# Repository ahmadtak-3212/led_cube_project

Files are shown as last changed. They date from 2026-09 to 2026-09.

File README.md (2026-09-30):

# LED cube (formerly "galina")

A **4 × 4 × 4 RGB LED cube**, built twice:

- **V1:** the cube is driven straight from an **FPGA**. The SystemVerilog design scans the cube one LED at a time: it selects a column through a shift register, selects a layer, and applies 8-bit PWM to each colour channel.
- **V2:** the cube sits on a custom KiCad PCB carrying an **Arduino Nano (ATmega328P)**. It uses a charlieplexing library and a set of animations.

🎥 **Demo video:** [`docs/images/Galina_Results.mp4`](docs/images/Galina_Results.mp4). The video is 720p; GitHub shows a download or preview link for it.

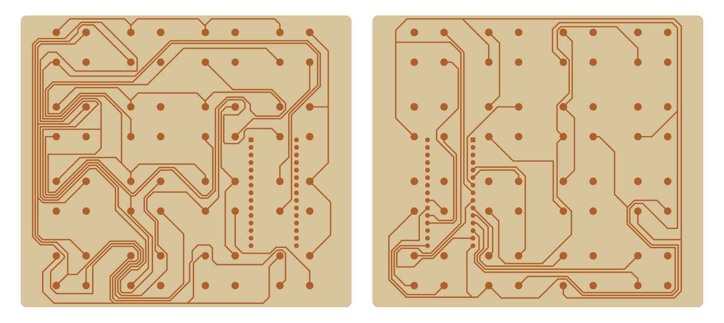
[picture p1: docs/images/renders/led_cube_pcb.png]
V2 PCB, top and bottom

<sub>V2 carrier PCB, rendered from <code>electrical/led_cube_pcb/GBR</code>.</sub>

## Status

| Area | Status |
|---|---|
| FPGA (V1) | ✅ Vivado project, testbenches and four prebuilt bitstreams |
| PCB (V2) | ✅ Routed; Gerbers exported, including a set prepared for a CNC etcher |
| Firmware (V2) | ✅ Animations running (see video) |
| Mechanical | ✅ PCB case, soldering jig, cut files |

## Repository layout

```
led_cube_project/
├── fpga/led_cube_v1/              Vivado project "Galina" (V1)
│   ├── Galina.xpr
│   ├── Galina.srcs/sources_1/new/ top_level.sv, led_driver_fsm.sv, write.sv, pwm.sv
│   ├── Galina.srcs/sources_1/ip/  clk_wiz_0 (clocking wizard)
│   ├── Galina.srcs/sim_1/         testbenches
│   ├── Galina.srcs/constrs_1/     .xdc constraints
│   ├── wcfg/                      saved waveform views for each testbench
│   └── runs/*.bit                 prebuilt bitstreams
├── electrical/led_cube_pcb/       KiCad 6 PCB for V2 (+ GBR/ Gerbers)
├── firmware/led_cube_firmware/    PlatformIO project for V2 (Arduino Nano)
├── mechanical/
│   ├── cad/                       SolidWorks: cube parts, Soldering_Jig.SLDASM
│   ├── cam/                       3D-print (.3mf), CNC-etcher Gerbers
│   └── exports/                   STL (PCB case + cover), SVG (laser-cut soldering jig)
└── docs/images/Galina_Results.mp4
```

## V1: FPGA driver (`fpga/led_cube_v1`)

**Target:** Xilinx Artix-7 **XC7A100T-CSG324** (`xc7a100tcsg324-3`), using the Nexys A7 / Nexys 4 DDR pinout. The 100 MHz clock is on pin E3, the cube connects through Pmod headers **JA** and **JB**, and `btnc`, `sw[15:0]` and `led[15:0]` come from the board.

**How it works:**

| Module | Role |
|---|---|
| `top_level.sv` | Holds the frame buffer `led_cube[4 layers][16 LEDs][24-bit RGB]` and a demo pattern generator. With `sw[0]` on, the cube cycles through white, red, green and blue every 4,000,000 clocks; `btnc` resets it. The board LEDs mirror the switches. |
| `led_driver_fsm.sv` | The scan FSM. For each LED in the current layer, it writes a one-hot 16-bit column pattern into the shift register and then runs a PWM slot for that pixel's RGB value. Each layer gets `MAX_CYCELS_PER_PLANE = 20833` clocks (16 slots of about 1302 clocks), after which it advances `z_level`. |
| `write.sv` | Shifts 16 bits out to a serial-in, parallel-out shift register chain. It drives SER, SRCLK and SRCLR, then pulses the latch. |
| `pwm.sv` | 8-bit PWM of the pixel's R, G and B bytes within one slot |
| `clk_wiz_0` | Divides the 100 MHz board clock down for the driver |

**Pmod pinout:**

| Pmod pin | Signal |
|---|---|
| `ja[0]` | shift-register serial data (SER) |
| `ja[1]` | shift clock (SRCLK) |
| `ja[2]` | shift-register clear (SRCLR, active low) |
| `ja[3]` | latch (RCLK) |
| `ja[4]`, `ja[5]`, `ja[6]` | red, green, blue PWM |
| `jb[3:0]` | one-hot layer select (z = 0…3) |

**Bitstreams** in `runs/` are `Brightness.bit`, `Checker.bit`, `EitherSide.bit` and `Full_Cube_Flash.bit`. Each is a different demo pattern.

**Rebuild or program:**
1. Open `Galina.xpr` in Vivado. The project was saved with **Vivado 2019.2**; newer versions will offer to upgrade it and the `clk_wiz_0` IP.
2. Run synthesis, implementation and bitstream generation.
3. Use Hardware Manager to program the board, or load one of the prebuilt `.bit` files.
4. To simulate, open any testbench in `sim_1` with its matching `.wcfg` from `wcfg/`.

## V2: Arduino carrier PCB (`electrical/led_cube_pcb`)

- KiCad 6, 2 layers, 111 × 98 mm.
- An **Arduino Nano v3** socket, sixteen **2 × 2 headers** (`J0,0` to `J3,3`, one per cube column, 4 leads each), and a 2-pin screw terminal for power.
- Gerbers are in `GBR/`. A copy set up for the desktop CNC etcher is in `mechanical/cam/CNC_Etcher/`.

## V2: firmware (`firmware/led_cube_firmware`)

| Setting | Value |
|---|---|
| Platform | `atmelavr`, board `nanoatmega328new` (Nano with the new bootloader), Arduino framework |
| Sources | `src/Firmware.ino` (animation loop), `src/cubeplex.h` (charlieplexing driver), `src/mappings.h` (pin-to-LED map), `src/niceTimer.h` |

The animations are `randomLed`, `planarSpin`, `fountian`, `trifade`, `shiftSquares`, `tunnel`, `chaseTheDot` and `planarFlop3D`.

```bash
cd firmware/led_cube_firmware
pio run -t upload          # Nano over USB
```

`platformio.ini` also points `lib_extra_dirs` at `~/Documents/Arduino/libraries`. The project doesn't need anything from there, because everything is in `src/`.

> **Credit:** `cubeplex.h`, `mappings.h`, `niceTimer.h` and the animation code in `Firmware.ino` come from **Asher Glick's** charlieplexed RGB cube library (Copyright © 2012 Asher Glick, BSD license; the full text is in `src/LICENCE` and in each file header). My work in V2 is the PCB, the build and the integration.

## Mechanical

| File | What |
|---|---|
| `cad/Soldering_Jig/Soldering_Jig.SLDASM` + `exports/svg/Soldering_Jig/*.svg` | Laser-cut jig that holds LEDs in a 4 × 4 grid while soldering each layer |
| `exports/stl/Galina_PCB_Case.STL`, `Galina_PCB_Cover.STL` | 3D-printed enclosure for the V2 PCB (`cam/3D_Printer/Galina_PCB_Casse.3mf` is the print project) |
| `cad/Galina/Parts/` | Cube part models |

## Reproducing

1. Laser-cut the soldering jig from the SVGs, then solder four 4 × 4 layers of common-lead RGB LEDs and stack them into columns.
2. **V2:** mill or order the PCB from `GBR/`, fit a Nano, plug each column into its 2 × 2 header, and flash the firmware.
3. **V1:** wire the Pmod pins as in the table above to a 16-bit shift-register column driver and four layer drivers, then program a bitstream.

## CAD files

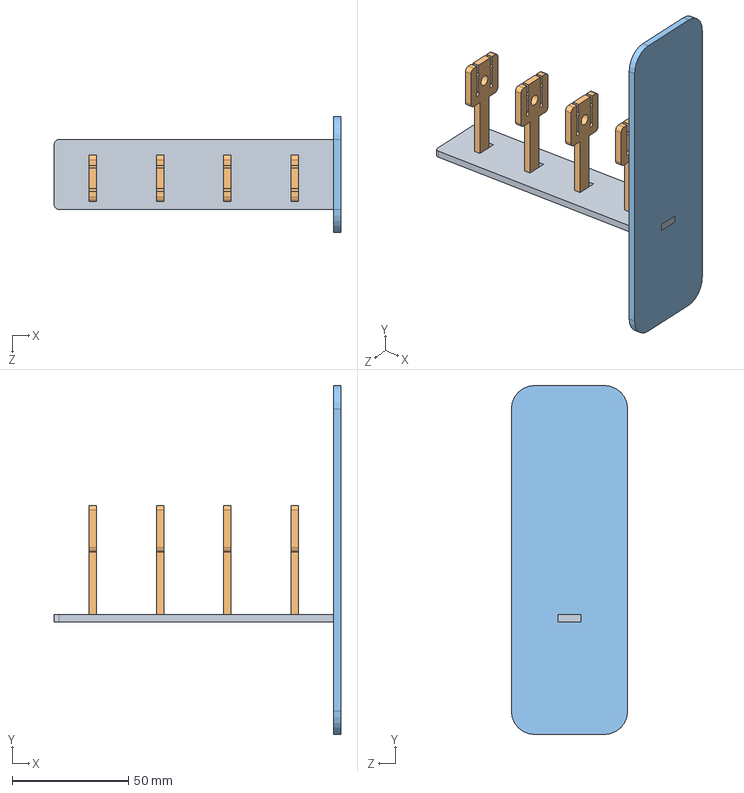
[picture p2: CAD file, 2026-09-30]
mechanical/cad/Soldering_Jig/Soldering_Jig.SLDASM
123.2 x 150.0 x 50.0 mm
LED_Holder_Jig
LED_Jig x 4
LED_Jig_Base

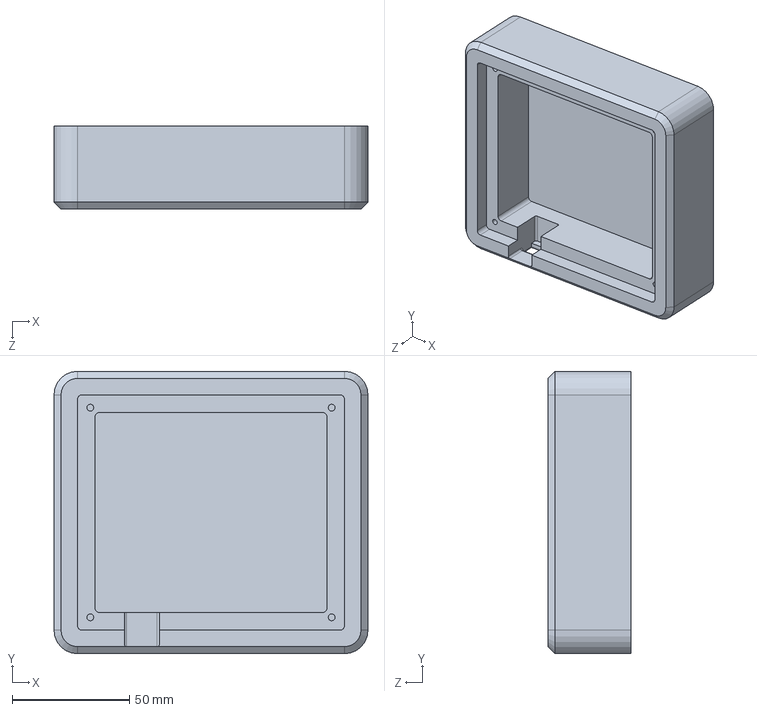
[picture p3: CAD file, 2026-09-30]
mechanical/cad/Galina/Parts/Galina_PCB_Case.SLDPRT
134.0 x 120.5 x 35.5 mm

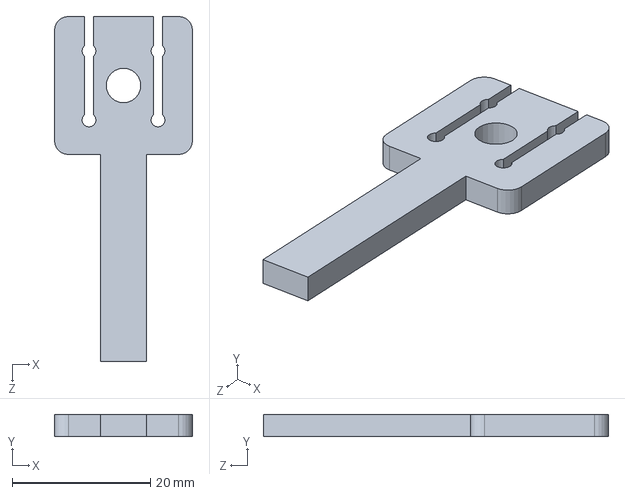
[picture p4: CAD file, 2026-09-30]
mechanical/cad/Soldering_Jig/Parts/LED_Jig.SLDPRT
20.0 x 3.20 x 50.0 mm

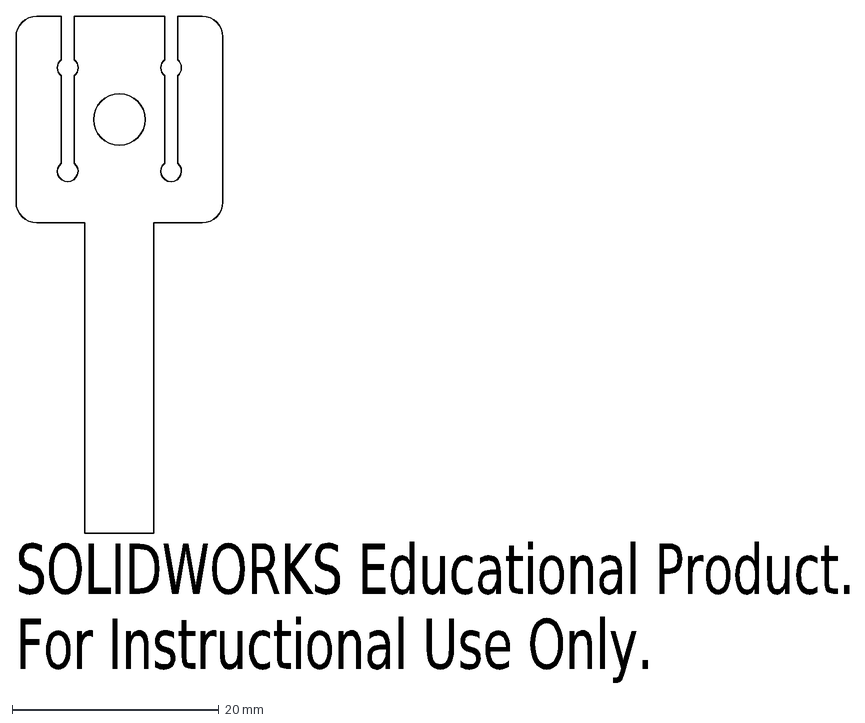
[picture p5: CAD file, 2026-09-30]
mechanical/exports/svg/Soldering_Jig/LED_Jig.DXF
SOLIDWORKS Educational Product.
For Instructional Use Only.

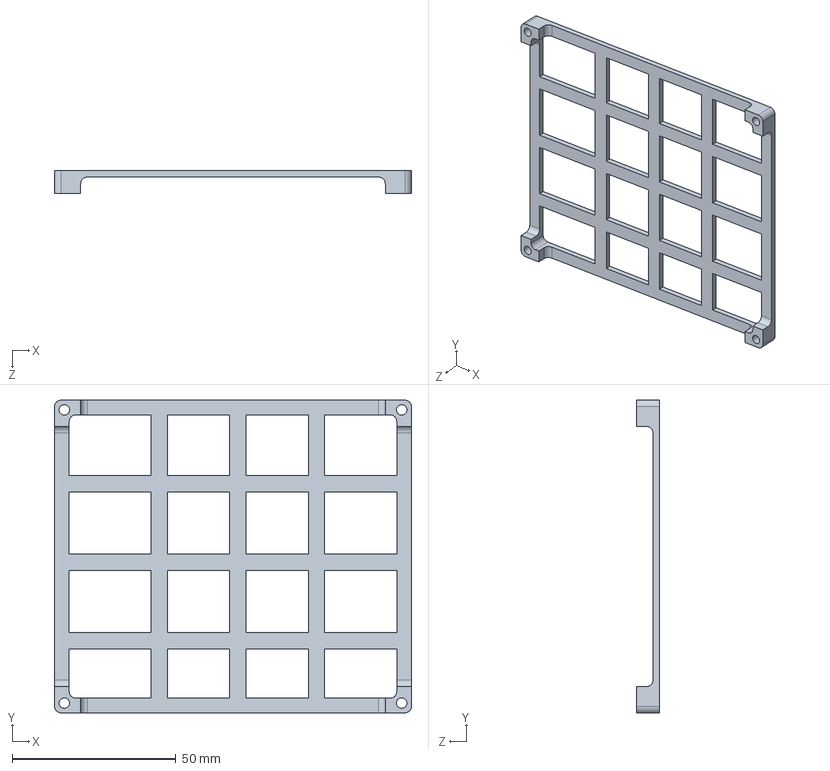
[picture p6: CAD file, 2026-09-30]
mechanical/cad/Galina/Parts/Galina_PCB_Cover.SLDPRT
109.0 x 95.5 x 7.00 mm

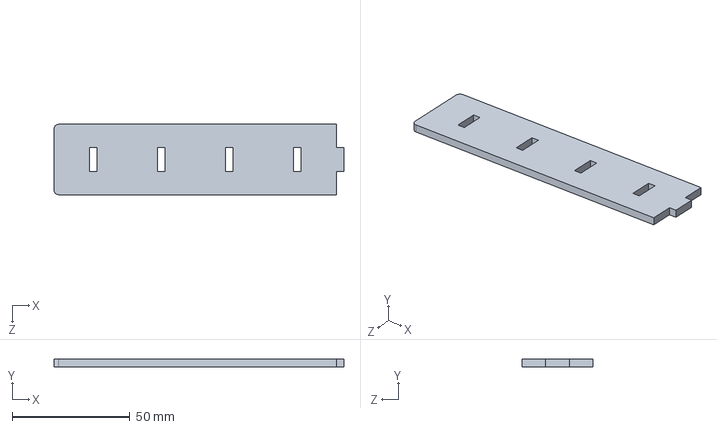
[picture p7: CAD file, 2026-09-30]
mechanical/cad/Soldering_Jig/Parts/LED_Holder_Jig.SLDPRT
123.2 x 3.20 x 30.0 mm

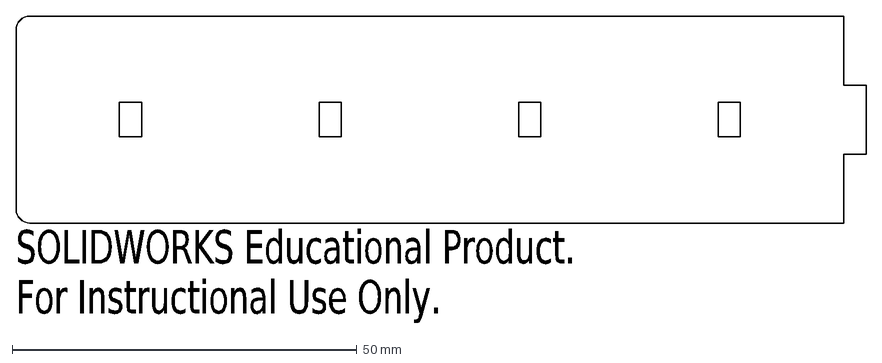
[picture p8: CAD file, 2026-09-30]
mechanical/exports/svg/Soldering_Jig/LED_Holder_Jig.DXF
SOLIDWORKS Educational Product.
For Instructional Use Only.

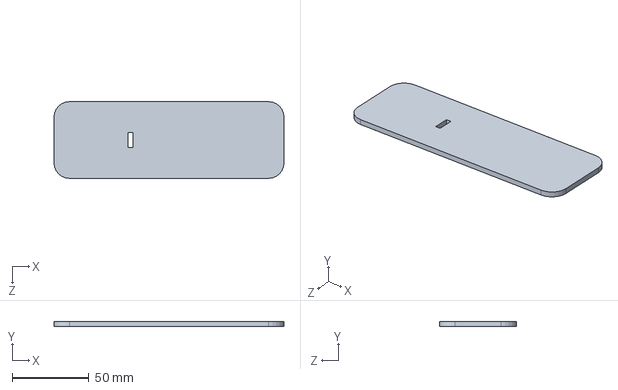
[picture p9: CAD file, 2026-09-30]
mechanical/cad/Soldering_Jig/Parts/LED_Jig_Base.SLDPRT
150.0 x 3.20 x 50.0 mm

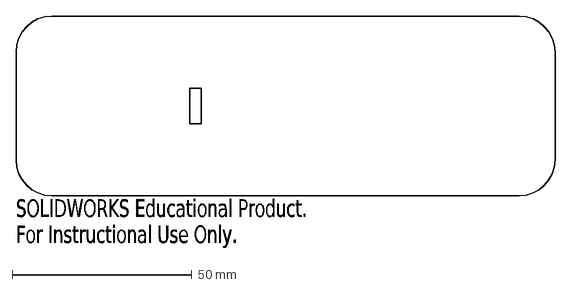
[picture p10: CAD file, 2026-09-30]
mechanical/exports/svg/Soldering_Jig/LED_Jig_Base.DXF
SOLIDWORKS Educational Product.
For Instructional Use Only.

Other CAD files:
mechanical/cam/3D_Printer/Galina_PCB_Casse.3mf
mechanical/exports/stl/Galina_PCB_Case.STL
mechanical/exports/stl/Galina_PCB_Cover.STL

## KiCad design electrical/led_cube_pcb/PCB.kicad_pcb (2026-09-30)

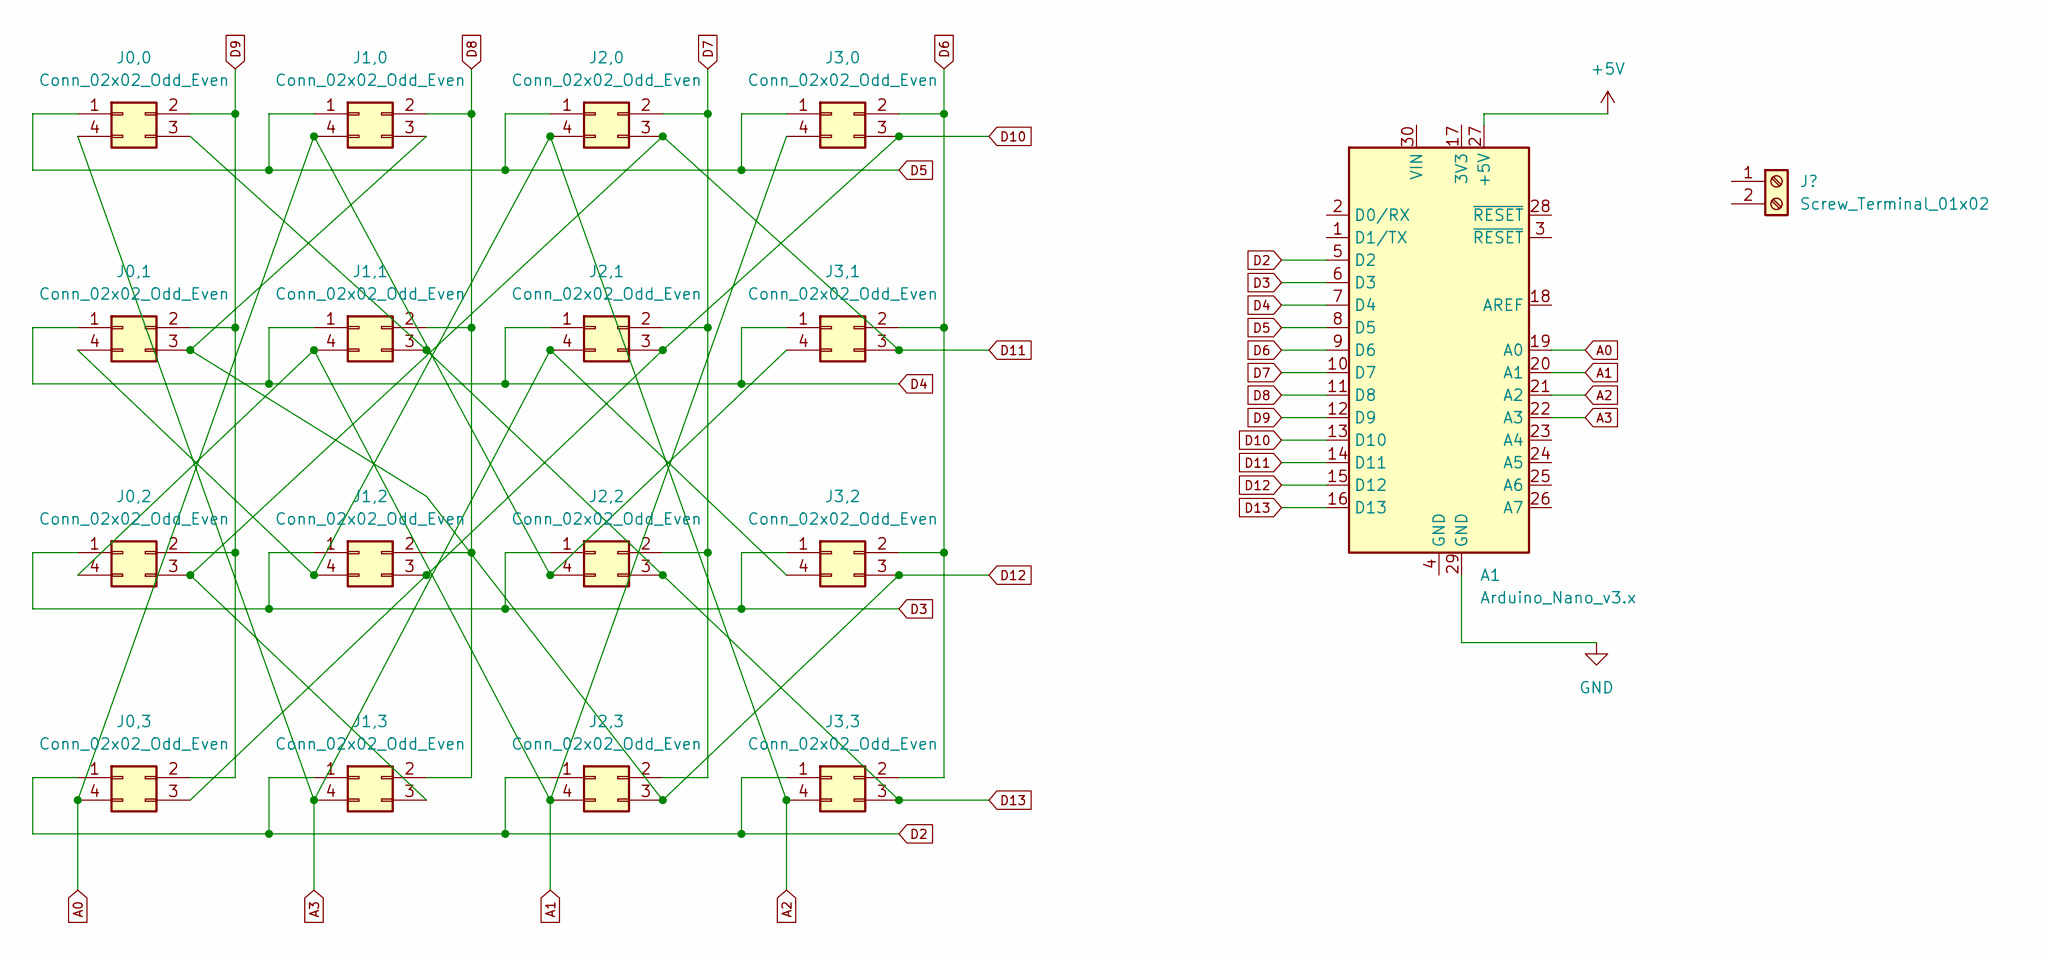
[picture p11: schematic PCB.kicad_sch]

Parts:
A1: Arduino_Nano_v3.x; Arduino_Nano
J0,0: Conn_02x02_Odd_Even
J0,1, J0,2, J0,3, J1,0, J1,1, J1,2, J1,3, J2,0, J2,1, J2,2, J2,3, J3,0, J3,1, J3,2, J3,3: Conn_02x02_Odd_Even; LED_D5.0mm-4_RGB_Square

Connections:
+5V: A1.27 (+5V)
A0: A1.19 (A0), J0,3.4, J1,0.4, J2,2.4, J3,1.4
A1: A1.20 (A1), J0,2.4, J1,1.4, J2,3.4, J3,0.4
A2: A1.21 (A2), J0,1.4, J1,2.4, J2,0.4, J3,3.4
A3: A1.22 (A3), J0,0.4, J1,3.4, J2,1.4, J3,2.4
D2: A1.5 (D2), J0,3.1, J1,3.1, J2,3.1, J3,3.1
D3: A1.6 (D3), J0,2.1, J1,2.1, J2,2.1, J3,2.1
D4: A1.7 (D4), J0,1.1, J1,1.1, J2,1.1, J3,1.1
D5: A1.8 (D5), J0,0.1, J1,0.1, J2,0.1, J3,0.1
D6: A1.9 (D6), J3,0.2, J3,1.2, J3,2.2, J3,3.2
D7: A1.10 (D7), J2,0.2, J2,1.2, J2,2.2, J2,3.2
D8: A1.11 (D8), J1,0.2, J1,1.2, J1,2.2, J1,3.2
D9: A1.12 (D9), J0,0.2, J0,1.2, J0,2.2, J0,3.2
D10: A1.13 (D10), J0,3.3, J1,2.3, J2,1.3, J3,0.3
D11: A1.14 (D11), J0,2.3, J1,3.3, J2,0.3, J3,1.3
D12: A1.15 (D12), J0,1.3, J1,0.3, J2,3.3, J3,2.3
D13: A1.16 (D13), J0,0.3, J1,1.3, J2,2.3, J3,3.3
GND: A1.29 (GND)

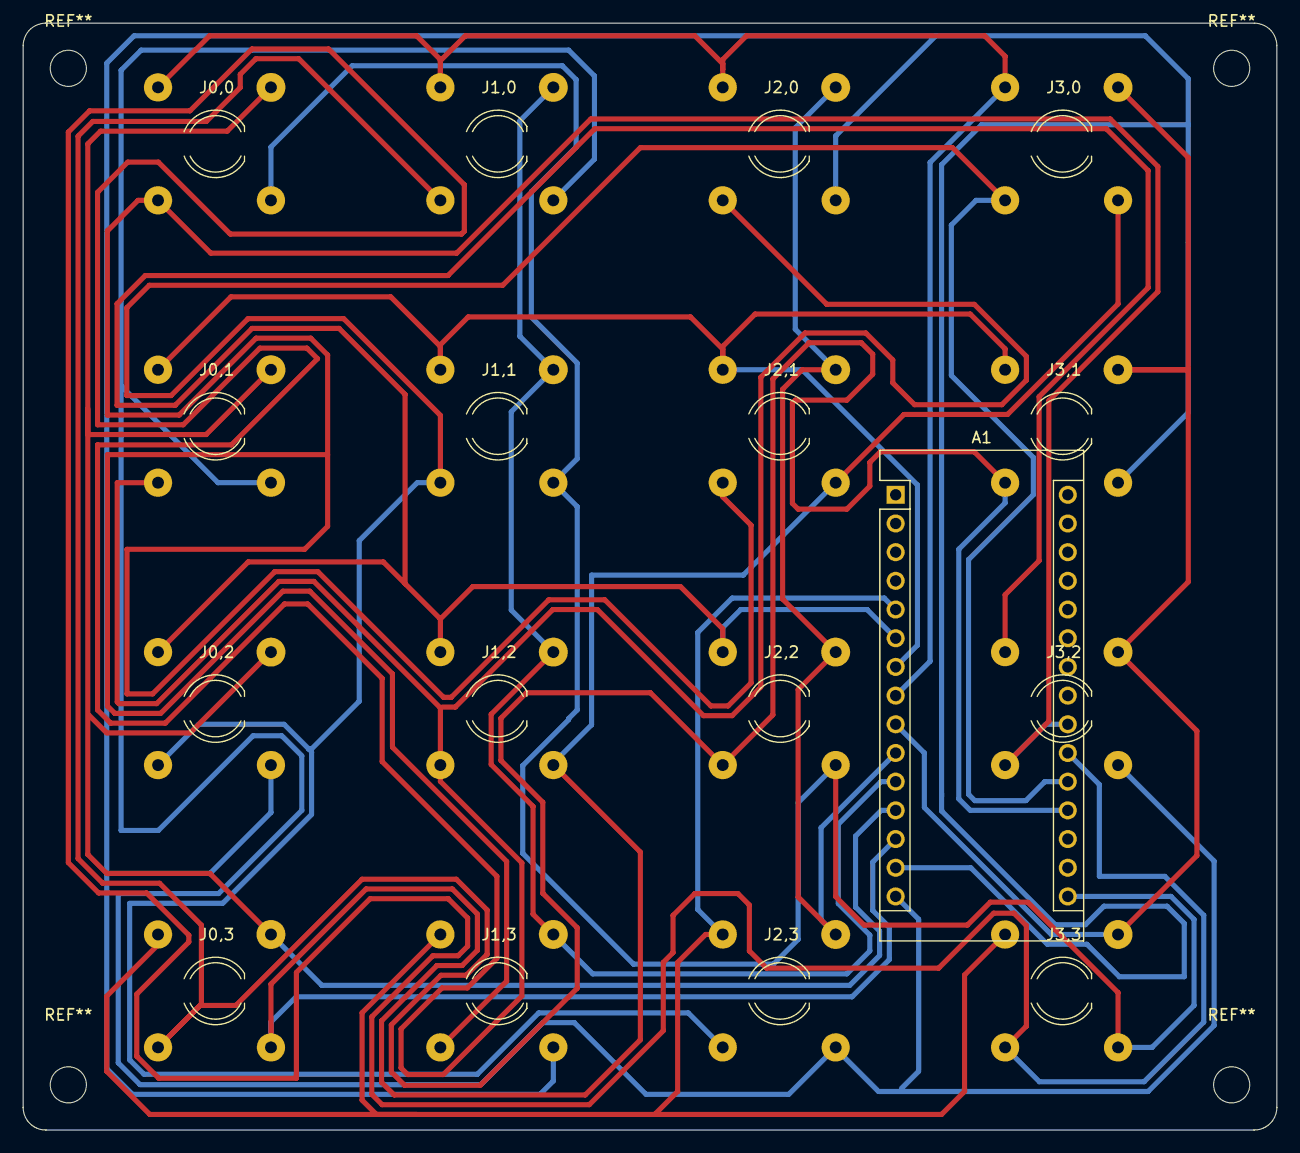
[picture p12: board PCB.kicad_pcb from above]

Board: 2 copper layers, 111.0 x 98.0 mm, 17 parts (0 on the bottom side), 16 nets.

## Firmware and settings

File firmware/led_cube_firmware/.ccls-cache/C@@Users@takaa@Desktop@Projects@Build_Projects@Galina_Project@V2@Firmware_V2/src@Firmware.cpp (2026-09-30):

/********************************** SIGNATURE *********************************\
|                                      ,,                                      |
|                     db             `7MM                                      |
|                    ;MM:              MM                                      |
|                   ,V^MM.    ,pP"Ybd  MMpMMMb.  .gP"Ya `7Mb,od8               |
|                  ,M  `MM    8I   `"  MM    MM ,M'   Yb  MM' "'               |
|                  AbmmmqMA   `YMMMa.  MM    MM 8M""""""  MM                   |
|                 A'     VML  L.   I8  MM    MM YM.    ,  MM                   |
|               .AMA.   .AMMA.M9mmmP'.JMML  JMML.`Mbmmd'.JMML.                 |
|                                                                              |
|                                                                              |
|                                  ,,    ,,                                    |
|                      .g8"""bgd `7MM    db        `7MM                        |
|                    .dP'     `M   MM                MM                        |
|                    dM'       `   MM  `7MM  ,p6"bo  MM  ,MP'                  |
|                    MM            MM    MM 6M'  OO  MM ;Y                     |
|                    MM.    `7MMF' MM    MM 8M       MM;Mm                     |
|                    `Mb.     MM   MM    MM YM.    , MM `Mb.                   |
|                      `"bmmmdPY .JMML..JMML.YMbmd'.JMML. YA.                  |
|                                                                              |
\******************************************************************************/
/*********************************** LICENCE **********************************\
| Copyright (c) 2012, Asher Glick                                              |
| All rights reserved.                                                         |
|                                                                              |
| Redistribution and use in source and binary forms, with or without           |
| modification, are permitted provided that the following conditions are met:  |
|                                                                              |
| * Redistributions of source code must retain the above copyright notice,     |
|   this list of conditions and the following disclaimer.                      |
| * Redistributions in binary form must reproduce the above copyright notice,  |
|   this list of conditions and the following disclaimer in the documentation  |
|   and/or other materials provided with the distribution.                     |
|                                                                              |
| THIS SOFTWARE IS PROVIDED BY THE COPYRIGHT HOLDERS AND CONTRIBUTORS "AS IS"  |
| AND ANY EXPRESS OR IMPLIED WARRANTIES, INCLUDING, BUT NOT LIMITED TO, THE    |
| IMPLIED WARRANTIES OF MERCHANTABILITY AND FITNESS FOR A PARTICULAR PURPOSE   |
| ARE DISCLAIMED. IN NO EVENT SHALL THE COPYRIGHT HOLDER OR CONTRIBUTORS BE    |
| LIABLE FOR ANY DIRECT, INDIRECT, INCIDENTAL, SPECIAL, EXEMPLARY, OR          |
| CONSEQUENTIAL DAMAGES (INCLUDING, BUT NOT LIMITED TO, PROCUREMENT OF         |
| SUBSTITUTE GOODS OR SERVICES; LOSS OF USE, DATA, OR PROFITS; OR BUSINESS     |
| INTERRUPTION) HOWEVER CAUSED AND ON ANY THEORY OF LIABILITY, WHETHER IN      |
| CONTRACT, STRICT LIABILITY, OR TORT (INCLUDING NEGLIGENCE OR OTHERWISE)      |
| ARISING IN ANY WAY OUT OF THE USE OF THIS SOFTWARE, EVEN IF ADVISED OF THE   |
| POSSIBILITY OF SUCH DAMAGE.                                                  |
\******************************************************************************/

#include "cubeplex.h"

int color = red;


void setup() {
  initCube();
  
  // how many secconds until the animation is told to progress
  animationMax = 10;
}
void loop() {
  planarSpin();
  fountian();
  trifade();
  shiftSquares();
  tunnel();
  chaseTheDot();
  planarFlop3D();
}

/********************************* PLANAR SPIN ********************************\
| A plane of light spins around the virtical center of the cube and changes    |
| colors after a certian number of rotations                                   |
|                                                                              |
| Written By: Asher Glick                                                      |
\******************************************************************************/
void planarSpin() {
  continuePattern = true;
  int animationSpeed = 50;
  int spinsPerColor = 5; // a spin is actually half a revolution
  while (continuePattern) {
    int x = 0;
    int y = 0;
    for (int i = 0; i < spinsPerColor; i++) {
      for (int x = 0; x < 3; x++) {
        drawLine(color,x,0,0,3-x,3,0);
        drawLine(color,x,0,1,3-x,3,1);
        drawLine(color,x,0,2,3-x,3,2);
        drawLine(color,x,0,3,3-x,3,3);
        flushBuffer();
        clearBuffer();
        delay(animationSpeed);
      }
      for (int y = 0; y < 3; y++) {
        drawLine(color,3,y,0,0,3-y,0);
        drawLine(color,3,y,1,0,3-y,1);
        drawLine(color,3,y,2,0,3-y,2);
        drawLine(color,3,y,3,0,3-y,3);
        flushBuffer();
        clearBuffer();
        delay(animationSpeed);
      }
    }
    color = nextColor(color);
  }
}

/********************************** FOUNTIAN **********************************\
| Light shoots up the middle of the cube then once it reaches the top fall     |
| back down on the outside of the cube. After it hits the bottom it changes    |
| color and starts again                                                       |
|                                                                              |
| Written By: Asher Glick                                                      |
\******************************************************************************/
void fountian() {
  continuePattern = true;
  int animationSpeed = 100;
  while (continuePattern) {
    for (int z = 0; z <= 3; z++) {
      drawBoxWalls(color,1,1,z,2,2,z);
      flushBuffer();
      clearBuffer();
      delay(animationSpeed);
    }
    for (int z = 3; z >= 0; z--) {
      drawBoxWalls(color,0,0,z,3,3,z);
      flushBuffer();
      clearBuffer();
      delay(animationSpeed);
    }
    color=nextColor(color);
  }
}

/********************************** TRI-FADE **********************************\
| This animation fades through the red green and blue colors of the leds       |
| creating different mixtures of each of the colors.                           |
|                                                                              |
| Written By: Asher Glick                                                      |
\******************************************************************************/
void trifade() {
  continuePattern = true;
  int animationSpeed = 100;
  while (continuePattern) {
    // blue fade out, red fade in
    for (int i = 1; i <= 8; i++) {
      drawBox(blue,9-i,0,0,0,3,3,3);
      drawBox(red,i,0,0,0,3,3,3);
      flushBuffer();
      clearBuffer();
      delay(animationSpeed);
    }
    // red fade out, green fade in
    for (int i = 1; i <= 8; i++) {
      drawBox(red,9-i,0,0,0,3,3,3);
      drawBox(green,i,0,0,0,3,3,3);
      flushBuffer();
      clearBuffer();
      delay(animationSpeed);
    }
    // green fade out, blue fade in
    for (int i = 1; i <= 8; i++) {
      drawBox(green,9-i,0,0,0,3,3,3);
      drawBox(blue,i,0,0,0,3,3,3);
      flushBuffer();
      clearBuffer();
      delay(animationSpeed);
    }
  }
}

/******************************** SHIFT SQUARES *******************************\
| Three 2x2x2 squares start on the cube each a red green or blue. then they    |
| randomly move around the cube one at a time, if they crash into each other   |
| then then both leds turn on and while they occupy the same space they apear  |
| a different color                                                            |
|                                                                              |
| Written By: Asher Glick                                                      |
\******************************************************************************/
void shiftSquares() {
  int animationSpeed = 100;
  
  int blx = 2; // blue x
  int bly = 0; // blue y
  int blz = 0; // blue z
  
  int rdx = 0; // red x
  int rdy = 2; // red y
  int rdz = 0; // red z
  
  int gnx = 0; // green x
  int gny = 0; // green y
  int gnz = 2; // green z
  
  int * mover = &blx;
  continuePattern = true;
  
  while(continuePattern) {
    switch (random(0,9)) {
      case 0: mover = &blx; break;
      case 1: mover = &bly; break;
      case 2: mover = &blz; break;
      case 3: mover = &rdx; break;
      case 4: mover = &rdy; break;
      case 5: mover = &rdz; break;
      case 6: mover = &gnx; break;
      case 7: mover = &gny; break;
      case 8: mover = &gnz; break;
    }
    *mover = (((*mover)+2)%4)-1;
    drawBox(blue ,abs(blx),abs(bly),abs(blz),abs(blx)+1,abs(bly)+1,abs(blz)+1);
    drawBox(red  ,abs(gnx),abs(gny),abs(gnz),abs(gnx)+1,abs(gny)+1,abs(gnz)+1);
    drawBox(green,abs(rdx),abs(rdy),abs(rdz),abs(rdx)+1,abs(rdy)+1,abs(rdz)+1);
    flushBuffer();
    clearBuffer();
    delay(animationSpeed);
    *mover = (((*mover)+2)%4)-1;
    drawBox(blue ,abs(blx),abs(bly),abs(blz),abs(blx)+1,abs(bly)+1,abs(blz)+1);
    drawBox(red  ,abs(gnx),abs(gny),abs(gnz),abs(gnx)+1,abs(gny)+1,abs(gnz)+1);
    drawBox(green,abs(rdx),abs(rdy),abs(rdz),abs(rdx)+1,abs(rdy)+1,abs(rdz)+1);
    flushBuffer();
    clearBuffer();
    delay(animationSpeed*2);
  }
}

/*********************************** TUNNEL ***********************************\
|
\******************************************************************************/
void tunnel() {
  continuePattern = true;
  int animationSpeed =100;
  
  int color1[]  = {R,R,R,R,B,B,B,B};
  int bright1[] = {2,4,6,8,2,4,6,8};
  int color2[]  = {B,B,B,B,R,R,R,R};
//int bright2[] = {6,4,2,0,6,4,2,0};
  int bright2[] = {8,6,4,2,8,6,4,2};
  
  int index[]   = {0,1,2,3,4,5,6,7};
  
  while (continuePattern) {
    drawBoxWalls(color1[index[0]],bright1[index[0]],1,1,0,2,2,0);
    drawBoxWalls(color2[index[0]],bright2[index[0]],1,1,0,2,2,0);
    drawBoxWalls(color1[index[1]],bright1[index[1]],1,1,1,2,2,1);
    drawBoxWalls(color2[index[1]],bright2[index[1]],1,1,1,2,2,1);
    drawBoxWalls(color1[index[2]],bright1[index[2]],1,1,2,2,2,2);
    drawBoxWalls(color2[index[2]],bright2[index[2]],1,1,2,2,2,2);
    drawBoxWalls(color1[index[3]],bright1[index[3]],1,1,3,2,2,3);
    drawBoxWalls(color2[index[3]],bright2[index[3]],1,1,3,2,2,3);
    
    drawBoxWalls(color1[index[4]],bright1[index[4]],0,0,3,3,3,3);
    drawBoxWalls(color2[index[4]],bright2[index[4]],0,0,3,3,3,3);
    drawBoxWalls(color1[index[5]],bright1[index[5]],0,0,2,3,3,2);
    drawBoxWalls(color2[index[5]],bright2[index[5]],0,0,2,3,3,2);
    drawBoxWalls(color1[index[6]],bright1[index[6]],0,0,1,3,3,1);
    drawBoxWalls(color2[index[6]],bright2[index[6]],0,0,1,3,3,1);
    drawBoxWalls(color1[index[7]],bright1[index[7]],0,0,0,3,3,0);
    drawBoxWalls(color2[index[7]],bright2[index[7]],0,0,0,3,3,0);
    
    
    flushBuffer();
    clearBuffer();
    for (int i = 0; i < 8; i++){
      //index[i] = index[i]==7?0:index[i]+1;
      index[i] = (index[i]+1)%8;
    }
    delay(animationSpeed);
    
  }
}
/******************************** CHASE THE DOT *******************************\
| A single point of light moves around the cube randomly and changes colors    |
| when it tries to go out of bounds                                            |
|                                                                              |
| Inspired By: Jonah Glick                                                     |
| Written By: Asher Glick                                                      |
\******************************************************************************/
void chaseTheDot() {
  continuePattern = true;
  int animationSpeed = 100;
  
  int xpos = 0;
  int ypos = 0;
  int zpos = 0;
  
  while (continuePattern) {
    switch(random(0,6)) {
      case 0:
        if (xpos > 0) {xpos--;break;}
        else color=nextColor(color);
      case 1:
        if (xpos < 3) {xpos++;break;}
        else color=nextColor(color);
        xpos--; break;
        
      case 2:
        if (ypos > 0) {ypos--;break;}
        else color=nextColor(color);
      case 3:
        if (ypos < 3) {ypos++;break;}
        else color=nextColor(color);
        ypos--; break;
      
      case 4:
        if (zpos > 0) {zpos--;break;}
        else color=nextColor(color);
      case 5:
        if (zpos < 3) {zpos++;break;}
        else color=nextColor(color);
        zpos--; break;
    }
    drawLed(color,xpos,ypos,zpos);
    flushBuffer();
    clearBuffer();
    delay(animationSpeed);
  }
}
/********************************* PLANAR FLOP ********************************\
| 
\******************************************************************************/
/******************************* PLANAR FLOP 3D *******************************\
| Version 2 of the planar flop, doing more complicated maths and 3D vectors    |
| 'n stuff. Making this function found the bug of reversed z axis line drawing |
\******************************************************************************/
void planarFlop3D() {
  continuePattern = true;
  int animationSpeed = 50;
  while (continuePattern) {
    
    for (int y = 3; y>0; y--){
      for (int z = 0; z < 4; z++) drawLine(color,0,3,z,3,y,z);
      flushBuffer();
      clearBuffer();
      delay(animationSpeed);
    }
    for (int x = 3; x > 0; x--) {
      for (int z = 0; z < 4; z++) drawLine(color,0,3,z,x,0,z);
      flushBuffer();
      clearBuffer();
      delay(animationSpeed);
    }
    
    
    for (int x = 0; x < 3; x++) {
      for (int y = 0; y < 4; y++) drawLine(color,0,y,0,x,y,3);
      flushBuffer();
      clearBuffer();
      delay(animationSpeed);
    }
    for (int z = 3; z > 0; z--) {
      for (int y = 0; y < 4; y++) drawLine(color,0,y,0,3,y,z);
      flushBuffer();
      clearBuffer();
      delay(animationSpeed);
    }
    
    for (int z = 0; z < 3; z++) {
      for (int x = 0; x < 4; x++) drawLine(color,x,0,0,x,3,z);
      flushBuffer();
      clearBuffer();
      delay(animationSpeed);
    }
    for (int y = 3; y > 0; y--) {
      for (int x = 0; x < 4; x++) drawLine(color,x,0,0,x,y,3);
      flushBuffer();
      clearBuffer();
      delay(animationSpeed);
    }
    
    for (int y = 0; y < 3; y++) {
      for (int z = 0; z < 4; z++) drawLine(color,3,0,z,0,y,z);
      flushBuffer();
      clearBuffer();
      delay(animationSpeed);
    }
    for (int x = 0; x < 3; x++) {
      for (int z = 0; z < 4; z++) drawLine(color,3,0,z,x,3,z);
      flushBuffer();
      clearBuffer();
      delay(animationSpeed);
    }
    
    for (int x = 3; x > 0; x--) {
      for (int y = 0; y < 4; y++) drawLine(color,3,y,3,x,y,0);
      flushBuffer();
      clearBuffer();
      delay(animationSpeed);
    }
    for (int z = 0; z < 3; z++) {
      for (int y = 0; y < 4; y++) drawLine(color,3,y,3,0,y,z);
      flushBuffer();
      clearBuffer();
      delay(animationSpeed);
    }
    
    for (int z = 3; z > 0; z--) {
      for (int x = 0; x < 4; x++) drawLine(color,x,3,3,x,0,z);
      flushBuffer();
      clearBuffer();
      delay(animationSpeed);
    } 
    for (int y = 0; y < 3; y++) {
      for (int x = 0; x < 4; x++) drawLine(color,x,3,3,x,y,0);
      flushBuffer();
      clearBuffer();
      delay(animationSpeed);
    }
    color = nextColor(color);
  }
}

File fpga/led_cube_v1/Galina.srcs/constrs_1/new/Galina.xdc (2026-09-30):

## R1.0  2019-08-27
## all inputs/outputs changed to lowercase; arrays start with zero.
## system clock renamed to clk_100mhz
## ja, jb, jc, jd renamed to 0-7
## xa port renamed 0-3
## seven segments renamed to a,b,c,d,e,f,dp

## This file is a general .xdc for the Nexys4 DDR Rev. C
## To use it in a project:
## - uncomment the lines corresponding to used pins
## - rename the used ports (in each line, after get_ports) according to the top level signal names in the project

## Clock signal
set_property -dict { PACKAGE_PIN E3    IOSTANDARD LVCMOS33 } [get_ports { clk_100mhz }]; #IO_L12P_T1_MRCC_35 Sch=clk100mhz
create_clock -add -name sys_clk_pin -period 10.00 -waveform {0 5} [get_ports {clk_100mhz}];


##Switches

set_property -dict { PACKAGE_PIN J15   IOSTANDARD LVCMOS33 } [get_ports { sw[0] }]; #IO_L24N_T3_RS0_15 Sch=sw[0]
set_property -dict { PACKAGE_PIN L16   IOSTANDARD LVCMOS33 } [get_ports { sw[1] }]; #IO_L3N_T0_DQS_EMCCLK_14 Sch=sw[1]
set_property -dict { PACKAGE_PIN M13   IOSTANDARD LVCMOS33 } [get_ports { sw[2] }]; #IO_L6N_T0_D08_VREF_14 Sch=sw[2]
set_property -dict { PACKAGE_PIN R15   IOSTANDARD LVCMOS33 } [get_ports { sw[3] }]; #IO_L13N_T2_MRCC_14 Sch=sw[3]
set_property -dict { PACKAGE_PIN R17   IOSTANDARD LVCMOS33 } [get_ports { sw[4] }]; #IO_L12N_T1_MRCC_14 Sch=sw[4]
set_property -dict { PACKAGE_PIN T18   IOSTANDARD LVCMOS33 } [get_ports { sw[5] }]; #IO_L7N_T1_D10_14 Sch=sw[5]
set_property -dict { PACKAGE_PIN U18   IOSTANDARD LVCMOS33 } [get_ports { sw[6] }]; #IO_L17N_T2_A13_D29_14 Sch=sw[6]
set_property -dict { PACKAGE_PIN R13   IOSTANDARD LVCMOS33 } [get_ports { sw[7] }]; #IO_L5N_T0_D07_14 Sch=sw[7]
set_property -dict { PACKAGE_PIN T8    IOSTANDARD LVCMOS18 } [get_ports { sw[8] }]; #IO_L24N_T3_34 Sch=sw[8]
set_property -dict { PACKAGE_PIN U8    IOSTANDARD LVCMOS18 } [get_ports { sw[9] }]; #IO_25_34 Sch=sw[9]
set_property -dict { PACKAGE_PIN R16   IOSTANDARD LVCMOS33 } [get_ports { sw[10] }]; #IO_L15P_T2_DQS_RDWR_B_14 Sch=sw[10]
set_property -dict { PACKAGE_PIN T13   IOSTANDARD LVCMOS33 } [get_ports { sw[11] }]; #IO_L23P_T3_A03_D19_14 Sch=sw[11]
set_property -dict { PACKAGE_PIN H6    IOSTANDARD LVCMOS33 } [get_ports { sw[12] }]; #IO_L24P_T3_35 Sch=sw[12]
set_property -dict { PACKAGE_PIN U12   IOSTANDARD LVCMOS33 } [get_ports { sw[13] }]; #IO_L20P_T3_A08_D24_14 Sch=sw[13]
set_property -dict { PACKAGE_PIN U11   IOSTANDARD LVCMOS33 } [get_ports { sw[14] }]; #IO_L19N_T3_A09_D25_VREF_14 Sch=sw[14]
set_property -dict { PACKAGE_PIN V10   IOSTANDARD LVCMOS33 } [get_ports { sw[15] }]; #IO_L21P_T3_DQS_14 Sch=sw[15]


## LEDs

set_property -dict { PACKAGE_PIN H17   IOSTANDARD LVCMOS33 } [get_ports { led[0] }]; #IO_L18P_T2_A24_15 Sch=led[0]
set_property -dict { PACKAGE_PIN K15   IOSTANDARD LVCMOS33 } [get_ports { led[1] }]; #IO_L24P_T3_RS1_15 Sch=led[1]
set_property -dict { PACKAGE_PIN J13   IOSTANDARD LVCMOS33 } [get_ports { led[2] }]; #IO_L17N_T2_A25_15 Sch=led[2]
set_property -dict { PACKAGE_PIN N14   IOSTANDARD LVCMOS33 } [get_ports { led[3] }]; #IO_L8P_T1_D11_14 Sch=led[3]
set_property -dict { PACKAGE_PIN R18   IOSTANDARD LVCMOS33 } [get_ports { led[4] }]; #IO_L7P_T1_D09_14 Sch=led[4]
set_property -dict { PACKAGE_PIN V17   IOSTANDARD LVCMOS33 } [get_ports { led[5] }]; #IO_L18N_T2_A11_D27_14 Sch=led[5]
set_property -dict { PACKAGE_PIN U17   IOSTANDARD LVCMOS33 } [get_ports { led[6] }]; #IO_L17P_T2_A14_D30_14 Sch=led[6]
set_property -dict { PACKAGE_PIN U16   IOSTANDARD LVCMOS33 } [get_ports { led[7] }]; #IO_L18P_T2_A12_D28_14 Sch=led[7]
set_property -dict { PACKAGE_PIN V16   IOSTANDARD LVCMOS33 } [get_ports { led[8] }]; #IO_L16N_T2_A15_D31_14 Sch=led[8]
set_property -dict { PACKAGE_PIN T15   IOSTANDARD LVCMOS33 } [get_ports { led[9] }]; #IO_L14N_T2_SRCC_14 Sch=led[9]
set_property -dict { PACKAGE_PIN U14   IOSTANDARD LVCMOS33 } [get_ports { led[10] }]; #IO_L22P_T3_A05_D21_14 Sch=led[10]
set_property -dict { PACKAGE_PIN T16   IOSTANDARD LVCMOS33 } [get_ports { led[11] }]; #IO_L15N_T2_DQS_DOUT_CSO_B_14 Sch=led[11]
set_property -dict { PACKAGE_PIN V15   IOSTANDARD LVCMOS33 } [get_ports { led[12] }]; #IO_L16P_T2_CSI_B_14 Sch=led[12]
set_property -dict { PACKAGE_PIN V14   IOSTANDARD LVCMOS33 } [get_ports { led[13] }]; #IO_L22N_T3_A04_D20_14 Sch=led[13]
set_property -dict { PACKAGE_PIN V12   IOSTANDARD LVCMOS33 } [get_ports { led[14] }]; #IO_L20N_T3_A07_D23_14 Sch=led[14]
set_property -dict { PACKAGE_PIN V11   IOSTANDARD LVCMOS33 } [get_ports { led[15] }]; #IO_L21N_T3_DQS_A06_D22_14 Sch=led[15]
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

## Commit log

2026-09-30 LED cube: FPGA (V1), custom PCB + firmware (V2)
    V1: Vivado project with SystemVerilog LED driver, PWM, testbenches and bitstreams.
    V2: KiCad PCB, ATmega328 firmware (PlatformIO), CAD/CAM for case and soldering jig.
    Result video compressed to 720p.
    Claude-Session: https://claude.ai/code/session_011fcbtq5kvbvgwpsb6ou6yg
    [Galina_PCB_Case.SLDPRT, Galina_PCB_Case.STL, Galina_PCB_Casse.3mf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]
2026-09-30 Rewrite README with build, reproduction and design details; add board renders
    Claude-Session: https://claude.ai/code/session_011fcbtQ5KvbvgwPSb6oU6YG
